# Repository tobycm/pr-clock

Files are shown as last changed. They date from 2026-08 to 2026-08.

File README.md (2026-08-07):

# pr-clock

a fun mini clock as penticton robotics merch to help fundraise them team. please speeeeed we need this we kinda mulalesssss

[Onshape Design](https://cad.onshape.com/documents/a779cb0c2a8da46b7a35ad93/w/c98179c9c43a563153a7dced/e/182edd20046c9e435cdfa8a4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)

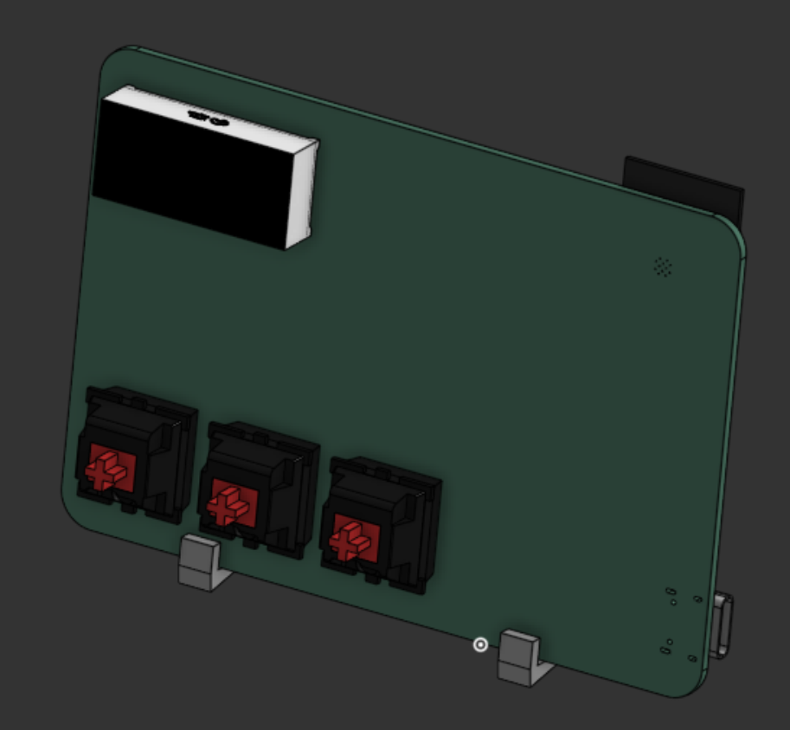
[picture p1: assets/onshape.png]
onshape overview


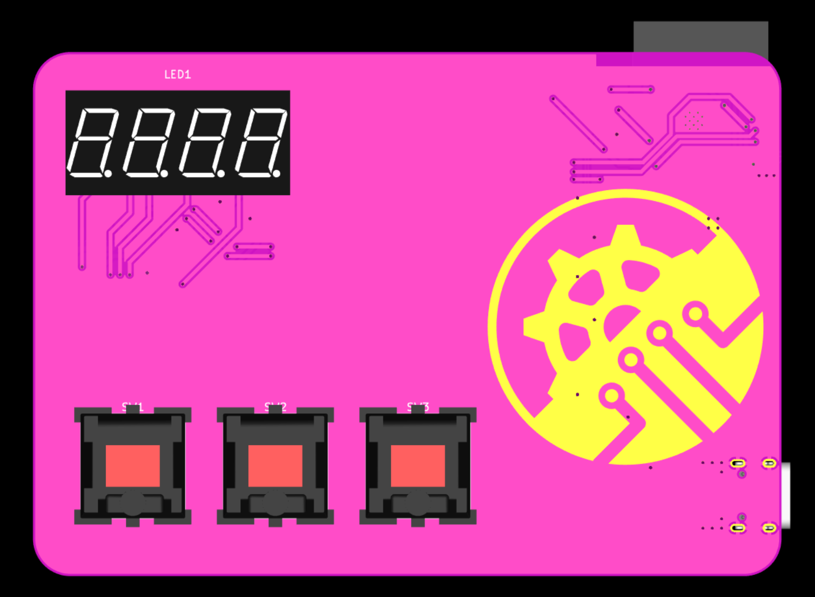
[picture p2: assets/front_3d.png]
front pcb 3d


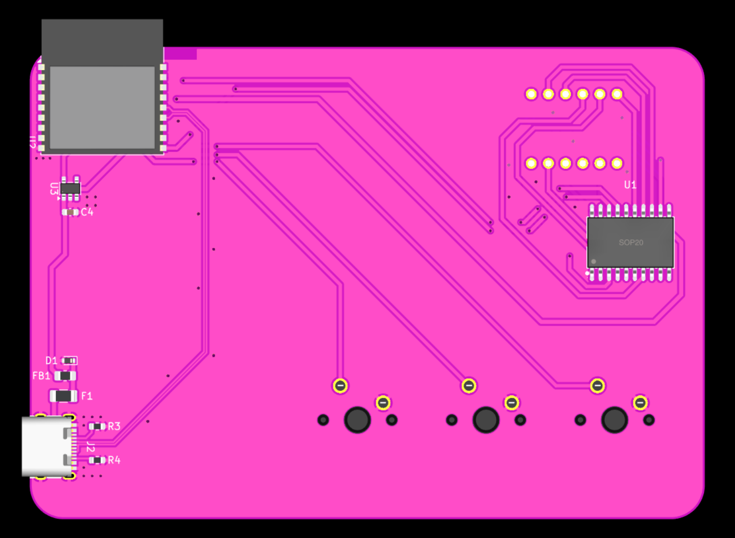
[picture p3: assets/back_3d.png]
back 3d pcb


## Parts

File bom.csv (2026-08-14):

Description | MPN | Manufacturer | Quantity | Unit Price($) | Extended Price($) | Product Link
4.5V~5.5V 500kHz I²C 80mA 20mA SOP-20-300mil Display Drivers RoHS | TM1637 | TM(Shenzhen Titan Micro Elec) | 6 | 0.2229 | 1.34 | https://www.lcsc.com/product-detail/C2962580.html
Red 4 60mW Common Anode Through Hole LED Character and Numeric RoHS | YD3641BRL-7.3 | YUDA ELECTRONIC | 6 | 0.3261 | 1.96 | https://www.lcsc.com/product-detail/C46614047.html
10uF ±10% 25V Ceramic Capacitor X5R 0805 | CL21A106KAYNNNE | Samsung Electro-Mechanics | 20 | 0.1056 | 2.11 | https://www.lcsc.com/product-detail/C15850.html
3.3V Positive Fixed SOT-23-5 Voltage Regulators - Linear, Low Drop Out (LDO) Regulators RoHS | ME6211C33M5G-N | MICRONE | 10 | 0.053 | 0.53 | https://www.lcsc.com/product-detail/C82942.html
2.4GHz ESP32-C3 Chip On-board PCB Antenna -105dBm VFQFN-32-EP RF Transceiver Modules and Modems RoHS | ESP32-C3-WROOM-02-N4 | ESPRESSIF | 1 | 3.2954 | 3.3 | https://www.lcsc.com/product-detail/C2934560.html
USB-C (USB TYPE-C) Receptacle Connector 16 Position Surface Mount, Right Angle | TYPE-C 16PIN 2MD(073) | SHOU HAN | 20 | 0.0707 | 1.41 | https://www.lcsc.com/product-detail/C2765186.html
5.1kΩ ±1% 100mW 0603 Thick Film Resistor | FRC0603F5101TS | FOJAN | 100 | 0.0027 | 0.27 | https://www.lcsc.com/product-detail/C2907044.html
2 Layers PCB |  |  | 1 | 3.1 | 3.1 | https://www.jlcpcb.com
JLCPCB Shipping |  |  | 1 | 1.5 | 1.5 | https://www.jlcpcb.com
LCSC Shipping |  |  | 1 | 18 | 18 | https://www.lcsc.com

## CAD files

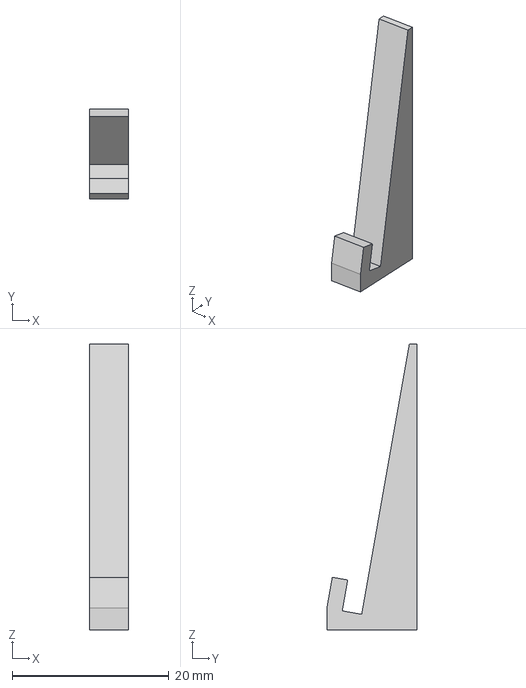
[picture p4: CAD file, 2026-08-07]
cad/Stand.step
5.00 x 11.5 x 36.5 mm

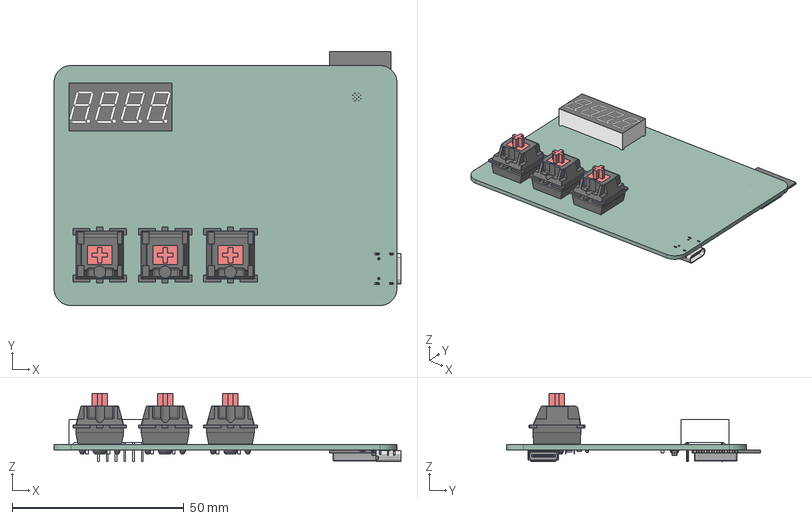
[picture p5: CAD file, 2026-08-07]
cad/pcb.step
101.2 x 74.1 x 19.8 mm
LED-SEG-TH_12P-L30.0-W14.0-H7.2-P2.54-S10.26-BL
R_0603_1608Metric x 2
Fuse_1206_3216Metric
D_SOD_523
R_0805_2012Metric
SOT-23-5
ESP32-C3-WROOM-02
C_0603_1608Metric
USB-C-SMD_TYPE-C-6PIN-2MD-073
pr-clock_PCB

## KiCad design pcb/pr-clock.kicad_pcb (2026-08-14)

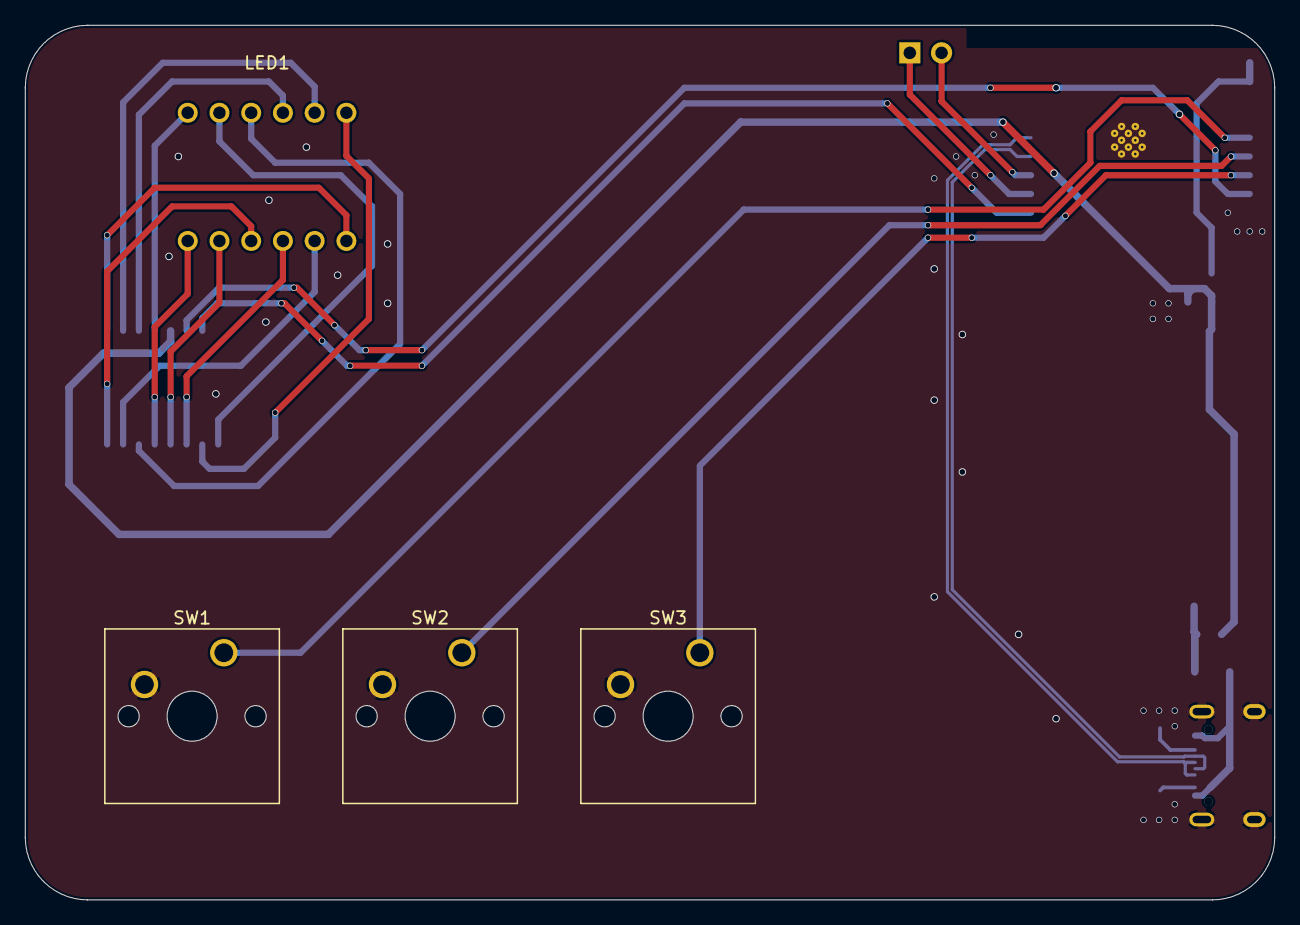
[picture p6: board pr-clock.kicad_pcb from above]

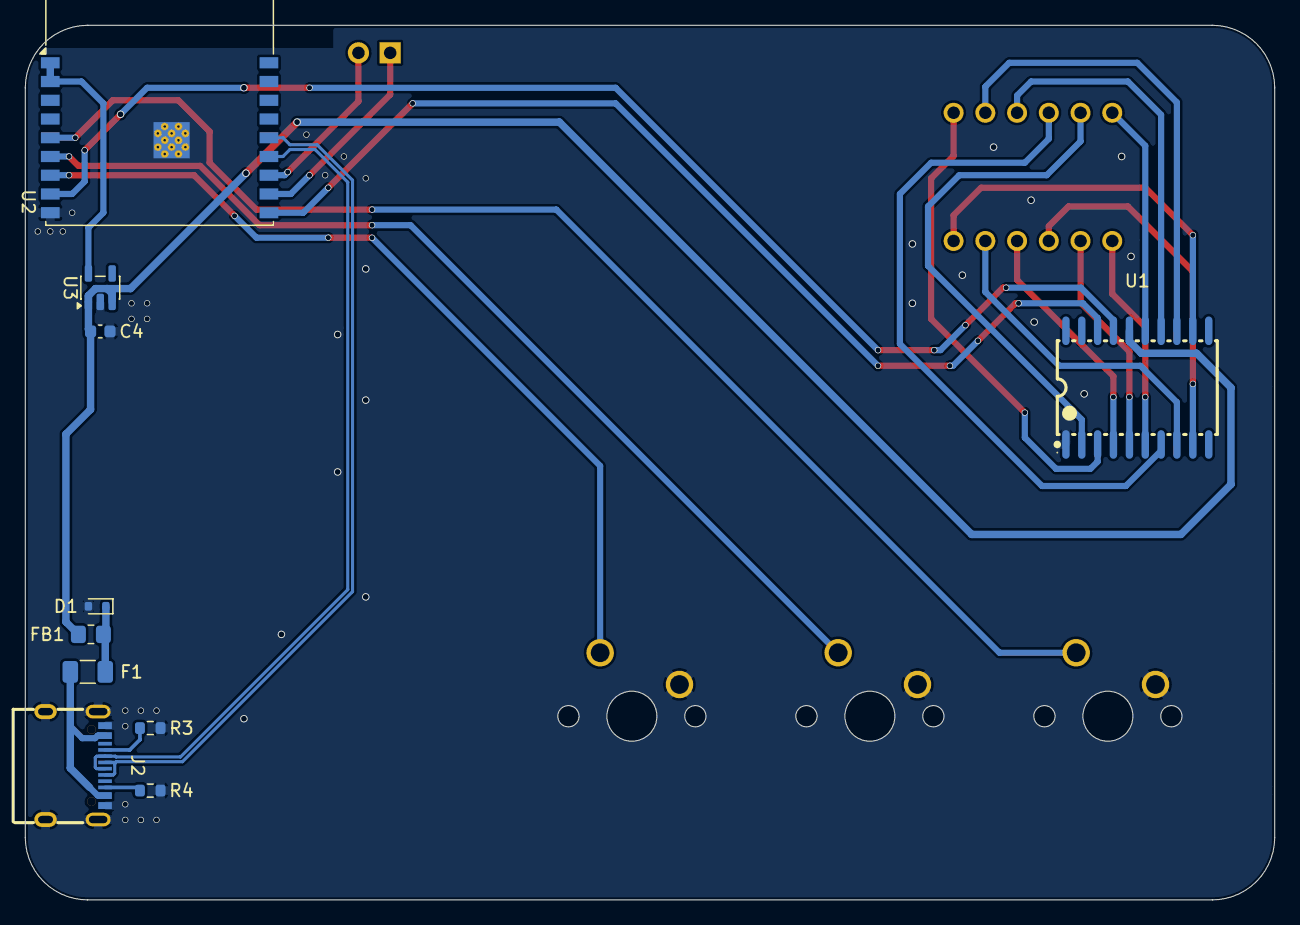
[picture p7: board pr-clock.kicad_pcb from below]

Board: 2 copper layers, 100.0 x 70.0 mm, 15 parts (10 on the bottom side), 28 nets.

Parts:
C4: 10u; C_0603_1608Metric
D1: 5V; D_SOD-523
F1: 2A; Fuse_1206_3216Metric
FB1: 220Ω@100MHz; R_0805_2012Metric_Pad1.20x1.40mm_HandSolder
J1: Conn_01x02; PinHeader_1x02_P2.54mm_Vertical
J2: USB_C_Receptacle_USB2.0_14P; USB-C-SMD_TYPE-C-16PIN-2MD-073
LED1: YD3641BRL-7.3; LED-SEG-TH_12P-L30.0-W14.0-P2.54-S10.26-BL
R3, R4: 5.1k; R_0603_1608Metric
SW1, SW2, SW3: SW_Push; SW_Cherry_MX_1.00u_PCB
U1: TM1637; SOP-20_L12.8-W7.5-P1.27-LS10.4-BL
U2: ESP32-C3-WROOM-02
U3: ME6211C33M5; SOT-23-5

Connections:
+3V3: U2.1 (3V3), U2.2 (EN), U3.5 (V_{OUT})
+5V: C4.1, FB1.2, U1.16 (VDD), U3.1 (V_{IN}), U3.3 (CE)
/BTN1: SW1.1, U2.5 (IO6)
/BTN2: SW2.1, U2.6 (IO7)
/BTN3: SW3.1, U2.7 (IO8)
/CLK: U1.18 (CLK), U2.10 (IO10)
/D+: J2.A6 (D+), J2.B6 (D+), U2.14 (IO19)
/D-: J2.A7 (D-), J2.B7 (D-), U2.13 (IO18)
/DIO: U1.17 (DIO), U2.8 (IO9)
/GRID1: LED1.12, U1.15 (GRID1)
/GRID2: LED1.9, U1.14 (GRID2)
/GRID3: LED1.8, U1.13 (GRID3)
/GRID4: LED1.6, U1.12 (GRID4)
/SEG1: LED1.11, U1.2 (SEG1/KS1)
/SEG2: LED1.7, U1.3 (SEG2/KS2)
/SEG3: LED1.4, U1.4 (SEG3/KS3)
/SEG4: LED1.2, U1.5 (SEG4/KS4)
/SEG5: LED1.1, U1.6 (SEG5/KS5)
/SEG6: LED1.10, U1.7 (SEG6/KS6)
/SEG7: LED1.5, U1.8 (SEG7/KS7)
/SEG8: LED1.3, U1.9 (SEG8/KS8)
GND: C4.2, D1.2 (A2), J2.A1 (GND), J2.B1 (GND), J2.SH (SHIELD), R3.1, R4.1, SW1.2, SW2.2, SW3.2, U1.1 (GND), U2.9 (GND), U2.19 (GND), U3.2 (V_{SS})
unnamed: D1.1 (A1), F1.2, FB1.1
unnamed: F1.1, J2.A4 (VBUS), J2.B4 (VBUS)
unnamed: J1.1, U2.11 (IO20/RXD)
unnamed: J1.2, U2.12 (IO21/TXD)
unnamed: J2.A5 (CC1), R3.2
unnamed: J2.B5 (CC2), R4.2

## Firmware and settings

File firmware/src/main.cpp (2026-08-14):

#include <Arduino.h>
#include <TM1637Display.h>

#define BTN1 6
#define BTN2 7
#define BTN3 8

#define DIO 9
#define CLK 10

// The amount of time (in milliseconds) between tests
#define TEST_DELAY 2000

const uint8_t SEG_DONE[] = {
    SEG_B | SEG_C | SEG_D | SEG_E | SEG_G,         // d
    SEG_A | SEG_B | SEG_C | SEG_D | SEG_E | SEG_F, // O
    SEG_C | SEG_E | SEG_G,                         // n
    SEG_A | SEG_D | SEG_E | SEG_F | SEG_G          // E
};

TM1637Display display(CLK, DIO);

void setup()
{
}

void loop()
{
  int k;
  uint8_t data[] = {0xff, 0xff, 0xff, 0xff};
  uint8_t blank[] = {0x00, 0x00, 0x00, 0x00};
  display.setBrightness(0x0f);

  // All segments on
  display.setSegments(data);
  delay(TEST_DELAY);

  // Selectively set different digits
  data[0] = display.encodeDigit(0);
  data[1] = display.encodeDigit(1);
  data[2] = display.encodeDigit(2);
  data[3] = display.encodeDigit(3);
  display.setSegments(data);
  delay(TEST_DELAY);

  /*
  for(k = 3; k >= 0; k--) {
  display.setSegments(data, 1, k);
  delay(TEST_DELAY);
  }
  */

  display.clear();
  display.setSegments(data + 2, 2, 2);
  delay(TEST_DELAY);

  display.clear();
  display.setSegments(data + 2, 2, 1);
  delay(TEST_DELAY);

  display.clear();
  display.setSegments(data + 1, 3, 1);
  delay(TEST_DELAY);

  // Show decimal numbers with/without leading zeros
  display.showNumberDec(0, false); // Expect: ___0
  delay(TEST_DELAY);
  display.showNumberDec(0, true); // Expect: 0000
  delay(TEST_DELAY);
  display.showNumberDec(1, false); // Expect: ___1
  delay(TEST_DELAY);
  display.showNumberDec(1, true); // Expect: 0001
  delay(TEST_DELAY);
  display.showNumberDec(301, false); // Expect: _301
  delay(TEST_DELAY);
  display.showNumberDec(301, true); // Expect: 0301
  delay(TEST_DELAY);
  display.clear();
  display.showNumberDec(14, false, 2, 1); // Expect: _14_
  delay(TEST_DELAY);
  display.clear();
  display.showNumberDec(4, true, 2, 2); // Expect: __04
  delay(TEST_DELAY);
  display.showNumberDec(-1, false); // Expect: __-1
  delay(TEST_DELAY);
  display.showNumberDec(-12); // Expect: _-12
  delay(TEST_DELAY);
  display.showNumberDec(-999); // Expect: -999
  delay(TEST_DELAY);
  display.clear();
  display.showNumberDec(-5, false, 3, 0); // Expect: _-5_
  delay(TEST_DELAY);
  display.showNumberHexEx(0xf1af); // Expect: f1Af
  delay(TEST_DELAY);
  display.showNumberHexEx(0x2c); // Expect: __2C
  delay(TEST_DELAY);
  display.showNumberHexEx(0xd1, 0, true); // Expect: 00d1
  delay(TEST_DELAY);
  display.clear();
  display.showNumberHexEx(0xd1, 0, true, 2); // Expect: d1__
  delay(TEST_DELAY);

  // Run through all the dots
  for (k = 0; k <= 4; k++)
  {
    display.showNumberDecEx(0, (0x80 >> k), true);
    delay(TEST_DELAY);
  }

  // Brightness Test
  for (k = 0; k < 4; k++)
    data[k] = 0xff;
  for (k = 0; k < 7; k++)
  {
    display.setBrightness(k);
    display.setSegments(data);
    delay(TEST_DELAY);
  }

  // On/Off test
  for (k = 0; k < 4; k++)
  {
    display.setBrightness(7, false); // Turn off
    display.setSegments(data);
    delay(TEST_DELAY);
    display.setBrightness(7, true); // Turn on
    display.setSegments(data);
    delay(TEST_DELAY);
  }

  // Done!
  display.setSegments(SEG_DONE);

  while (1)
    ;
}

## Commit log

2026-01-18 Initial KiCad commit
    [pr-clock.kicad_pcb, pr-clock.kicad_sch]
2026-01-18 add tm1637 chip and display tube
    [pr-clock.kicad_sch]
2026-08-08 add bom
    [bom.csv]
2026-08-14 add test firmware and bom
    [bom.csv, pr-clock.kicad_pcb, pr-clock.kicad_sch]
